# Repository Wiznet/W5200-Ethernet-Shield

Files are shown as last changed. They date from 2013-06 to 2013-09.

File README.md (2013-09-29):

# W5200 Ethernet Shield
W5200 Ethernet Shield is compatible with Official [Arduino Ethernet Shield](http://arduino.cc/en/Main/ArduinoEthernetShield) and support fast SPI and 8 sockets. 

W5200 Ethernet Shield

## Hardware
These are PCB files for the W5200 Ethernet Shield for Arduino. The files were created in the free & low cost EagleCad software available from [CadSoft](http://www.cadsoftusa.com/download-eagle/?language=en).

## Software
You need to change the existing W5100 files to W5200 library files.

1. Install W5200 library
   Overwrite w5100.cpp, w5100.h to the "/libraries/Ethernet/utility" folder in your Arduino IDE. 

2. Using the W5200 library and evaluate existing Ethernet example.
   In the Arduino IDE, go to Files->Examples->Ethernet and open any example, compile and upload the file to Arduino board.

3. Note: libraries/Ethernet/Ethernet.h needs the following at line 10 instead of #define MAX_SOCK_NUM 4, since it doesn't #include "w5100.h" anymore:

 `#ifdef W5200`

 `#define MAX_SOCK_NUM 8`

 `#else`
 
 `#define MAX_SOCK_NUM 4`

 `#endif`

## Revision History
Initial Release : 10 June 2013

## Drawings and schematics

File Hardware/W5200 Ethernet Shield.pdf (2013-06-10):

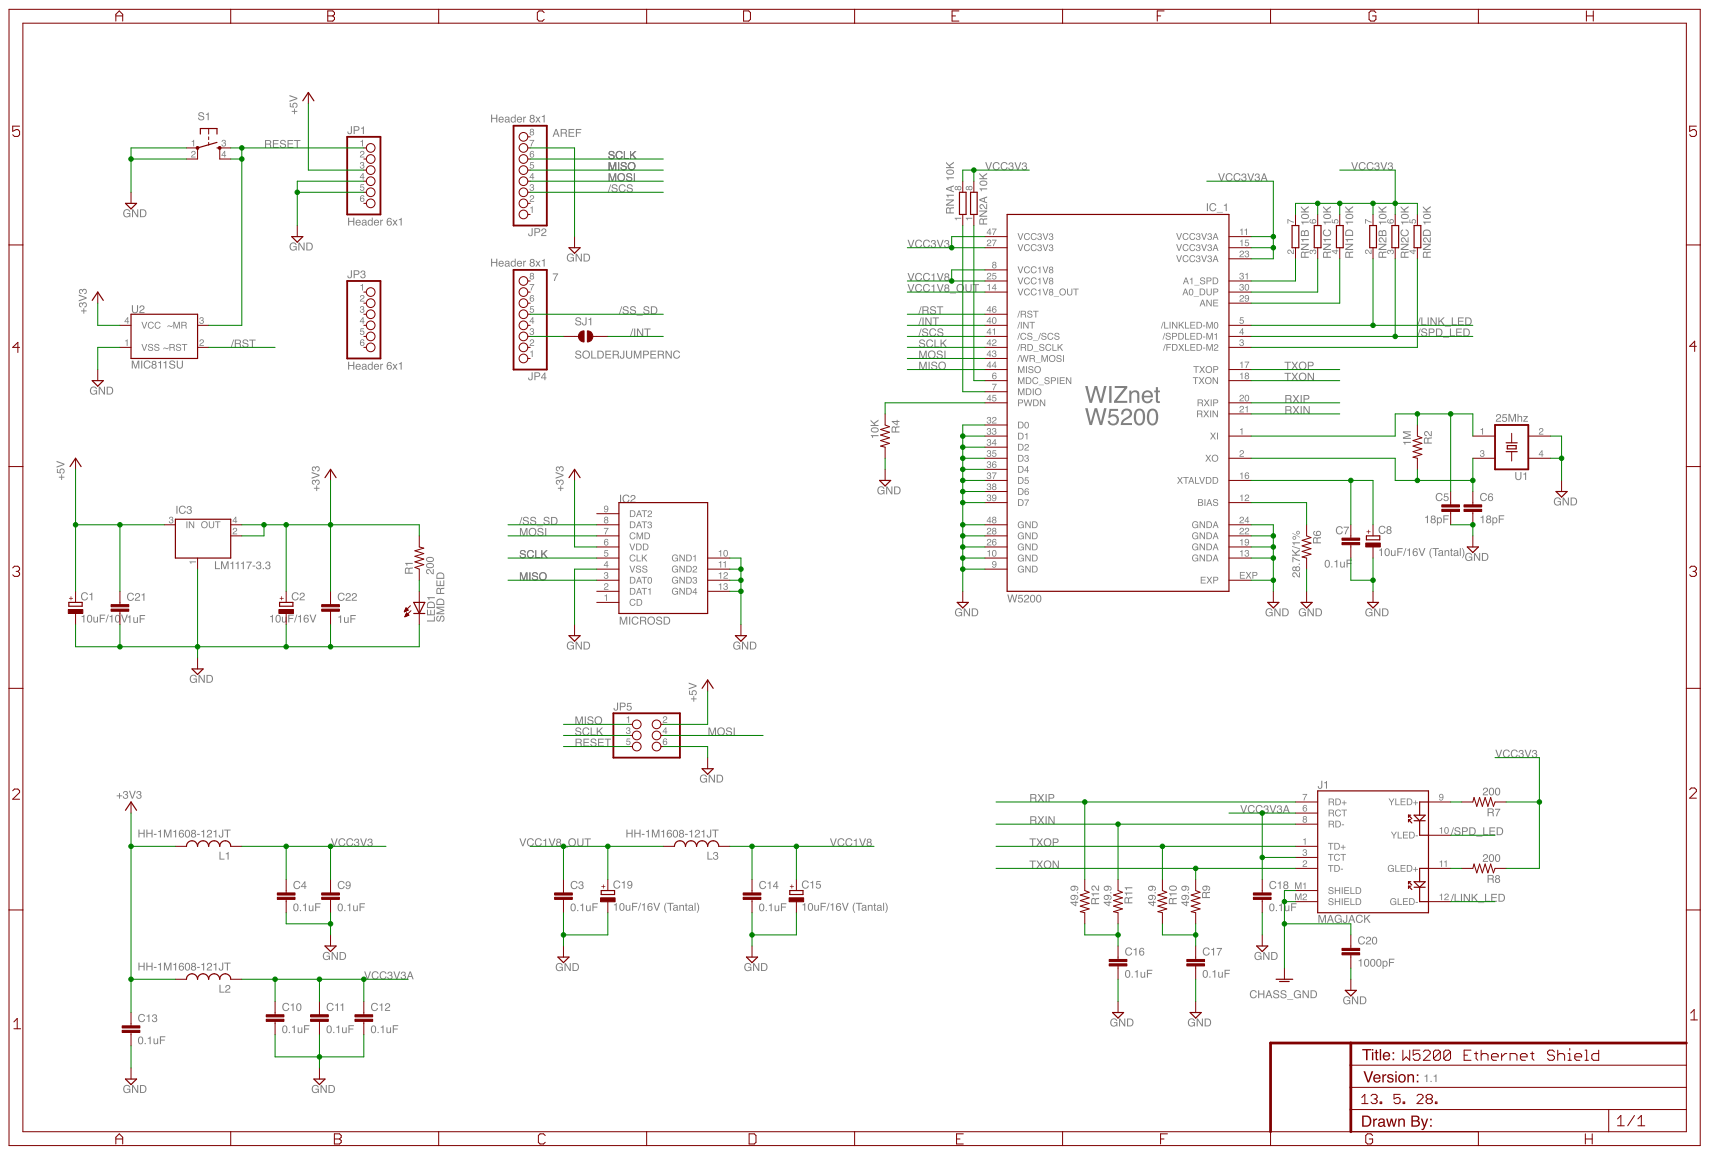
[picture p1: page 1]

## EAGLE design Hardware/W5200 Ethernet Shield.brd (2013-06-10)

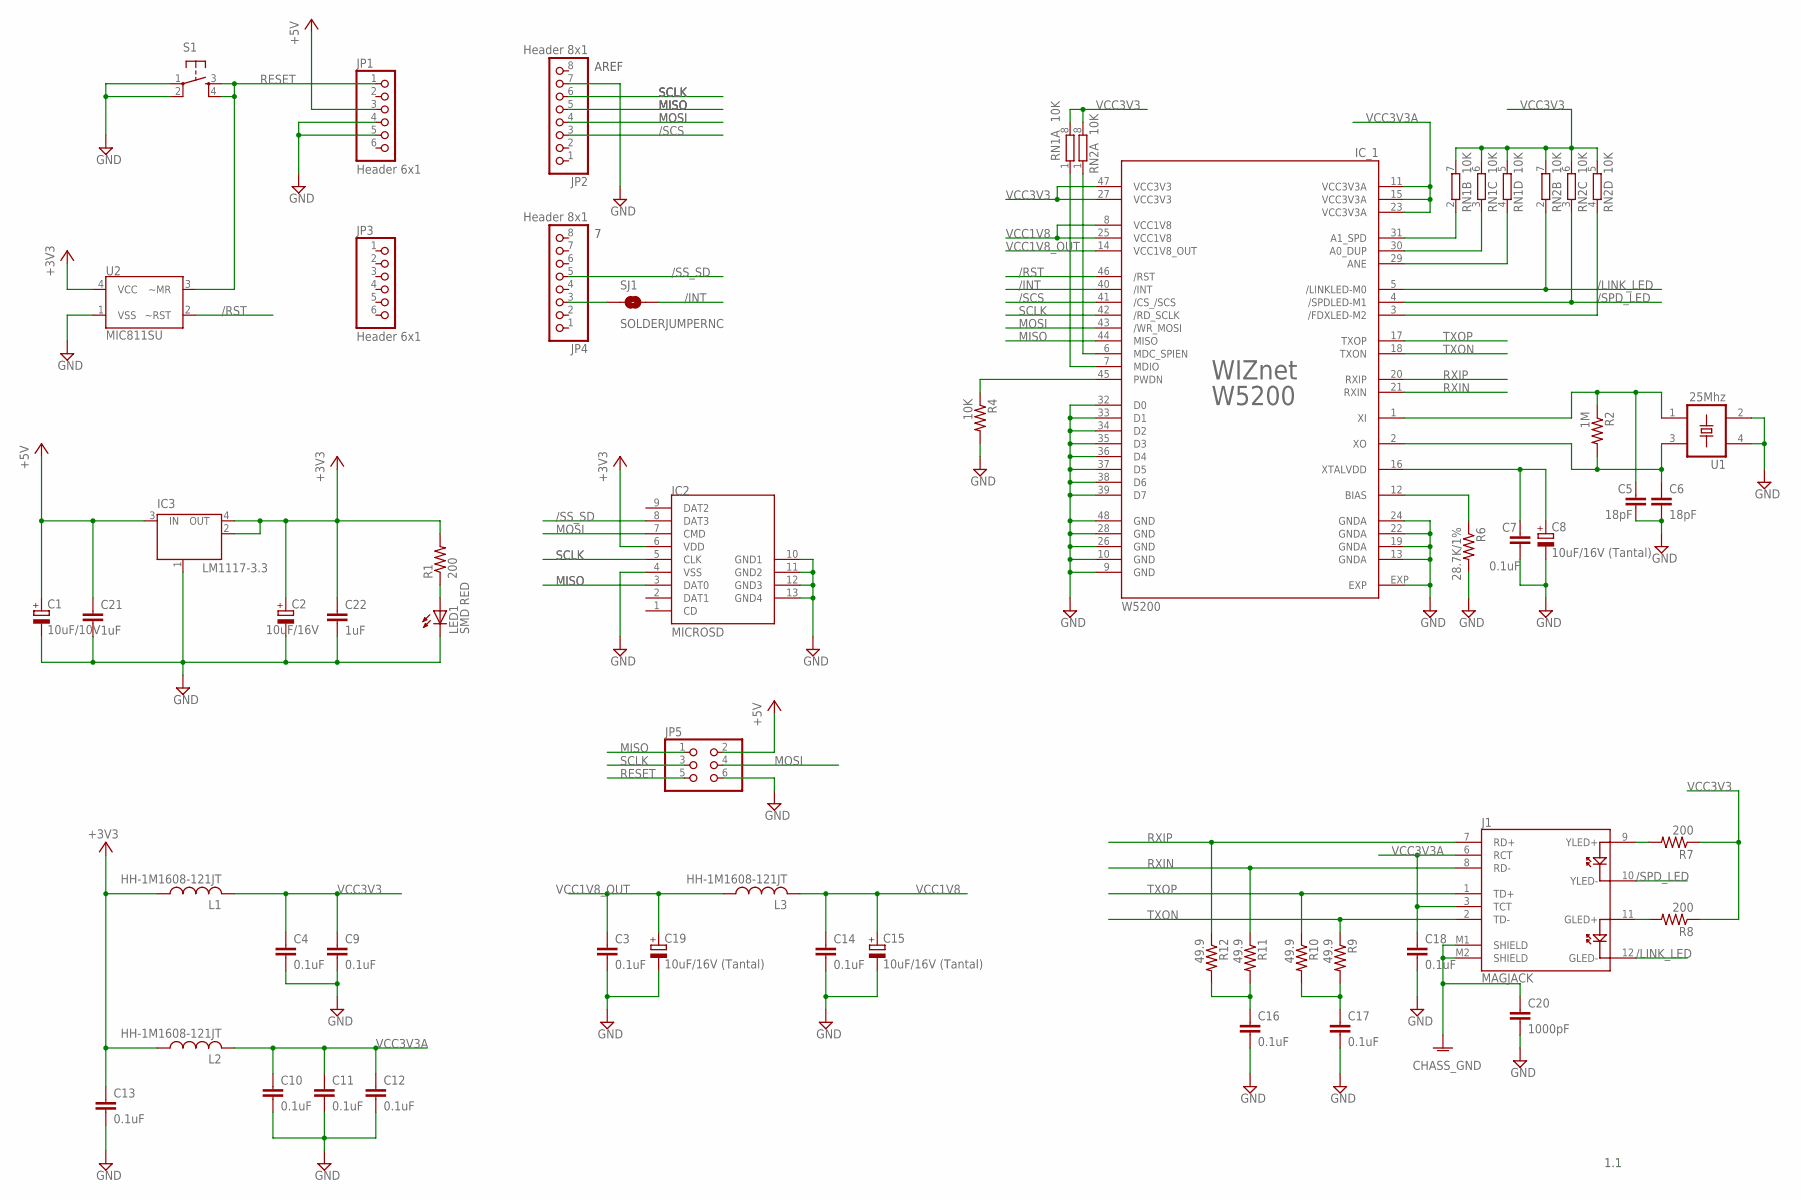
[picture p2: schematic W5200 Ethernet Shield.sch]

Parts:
C1: 10uF/10V; CT3216
C2: 10uF/16V; CT3216
C3, C4, C7, C9, C10, C11, C12, C13, C14, C16, C17, C18: 0.1uF; C0603
C5, C6: 18pF; C0603
C8, C15, C19: 10uF/16V (Tantal); CT3216
C20: 1000pF; C3225
C21, C22: 1uF; C0603
IC2: MICROSD; MSD_SYMBOL_MSDPAC
IC3: LM1117-3.3; SOT223
IC_1: W5200; QFN48
J1: MAGJACK
JP1, JP3: Header 6x1; 1X06
JP2, JP4: Header 8x1; 1X08
JP5: PINHD-2X3; 2X03
L1, L2, L3: HH-1M1608-121JT; L2012C
LED1: SMD RED; CHIP-LED0805
R1, R7, R8: 200; R0603
R2: 1M; R0603
R4: 10K; R0603
R6: 28.7K/1%; R0603
R9, R10, R11, R12: 49.9; R0603
RN1, RN2: 10K; EXBV8V
S1: TAC_SWITCHSMD; TACTILE_SWITCH_SMD
SJ1: SOLDERJUMPERNC; SJ_2S
U1: 25Mhz; CRYSTAL
U2: MIC811SU; SOT143

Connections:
+3V3: C2.+, C13.1, C22.1, IC2.6 (VDD), IC3.2 (OUT), IC3.4 (OUT), L1.1, L2.1, R1.2, U2.4 (VCC)
+5V: C1.+, C21.1, IC3.3 (IN), JP1.3, JP5.2
/INT: IC_1.40 (/INT), SJ1.2
/LINK_LED: IC_1.5 (/LINKLED-M0), J1.12 (GLED-), RN2.2 (1)
/RST: IC_1.46 (/RST), U2.2 (~RST)
/SCS: IC_1.41 (/CS_/SCS), JP2.3
/SPD_LED: IC_1.4 (/SPDLED-M1), J1.10 (YLED-), RN2.3 (1)
/SS_SD: IC2.8 (DAT3), JP4.5
GND: C1.-, C2.-, C3.2, C4.2, C5.2, C6.2, C7.2, C8.-, C9.2, C10.2, C11.2, C12.2, C13.2, C14.2, C15.-, C16.2, C17.2, C18.2, C19.-, C20.2, C21.2, C22.2, IC2.4 (VSS), IC2.10 (GND1), IC2.11 (GND2), IC2.12 (GND3), IC2.13 (GND4), IC3.1 (GND/ADJ), IC_1.9 (GND), IC_1.10 (GND), IC_1.13 (GNDA), IC_1.19 (GNDA), IC_1.22 (GNDA), IC_1.24 (GNDA), IC_1.26 (GND), IC_1.28 (GND), IC_1.32 (D0), IC_1.33 (D1), IC_1.34 (D2), IC_1.35 (D3), IC_1.36 (D4), IC_1.37 (D5), IC_1.38 (D6), IC_1.39 (D7), IC_1.48 (GND), IC_1.EXP, JP1.4, JP1.5, JP2.7, JP5.6, LED1.C, R4.2, R6.2, S1.1, S1.2, U1.2 (GND0), U1.4 (GND1), U2.1 (VSS)
GNDA: C20.1, J1.M1 (SHIELD), J1.M2 (SHIELD)
MISO: IC2.3 (DAT0), IC_1.44 (MISO), JP2.5, JP5.1
MOSI: IC2.7 (CMD), IC_1.43 (/WR_MOSI), JP2.4, JP5.4
unnamed: JP4.3, SJ1.1
unnamed: IC_1.31 (A1_SPD), RN1.2 (1)
unnamed: C6.1, IC_1.2 (XO), R2.2, U1.3 (OUT)
unnamed: C5.1, IC_1.1 (XI), R2.1, U1.1 (TRI)
unnamed: IC_1.30 (A0_DUP), RN1.3 (1)
unnamed: IC_1.29 (ANE), RN1.4 (1)
unnamed: J1.9 (YLED+), R7.2
unnamed: J1.11 (GLED+), R8.2
unnamed: IC_1.7 (MDIO), RN1.1
unnamed: IC_1.12 (BIAS), R6.1
unnamed: C7.1, C8.+, IC_1.16 (XTALVDD)
unnamed: C17.1, R9.2, R10.2
unnamed: LED1.A, R1.1
unnamed: C16.1, R11.2, R12.2
unnamed: IC_1.6 (MDC_SPIEN), RN2.1
unnamed: IC_1.3 (/FDXLED-M2), RN2.4 (1)
PWDN: IC_1.45 (PWDN), R4.1
RESET: JP1.1, JP5.5, S1.3, S1.4, U2.3 (~MR)
RXIN: IC_1.21 (RXIN), J1.8 (RD-), R11.1
RXIP: IC_1.20 (RXIP), J1.7 (RD+), R12.1
SCLK: IC2.5 (CLK), IC_1.42 (/RD_SCLK), JP2.6, JP5.3
TXON: IC_1.18 (TXON), J1.2 (TD-), R9.1
TXOP: IC_1.17 (TXOP), J1.1 (TD+), R10.1
VCC1V8: C14.1, C15.+, IC_1.8 (VCC1V8), IC_1.25 (VCC1V8), L3.2
VCC1V8_OUT: C3.1, C19.+, IC_1.14 (VCC1V8_OUT), L3.1
VCC3V3: C4.1, C9.1, IC_1.27 (VCC3V3), IC_1.47 (VCC3V3), L1.2, R7.1, R8.1, RN1.5 (2), RN1.6 (2), RN1.7 (2), RN1.8 (2), RN2.5 (2), RN2.6 (2), RN2.7 (2), RN2.8 (2)
VCC3V3A: C10.1, C11.1, C12.1, C18.1, IC_1.11 (VCC3V3A), IC_1.15 (VCC3V3A), IC_1.23 (VCC3V3A), J1.3 (TCT), J1.6 (RCT), L2.2

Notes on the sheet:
AREF
SCLK
MISO
MOSI
1.1

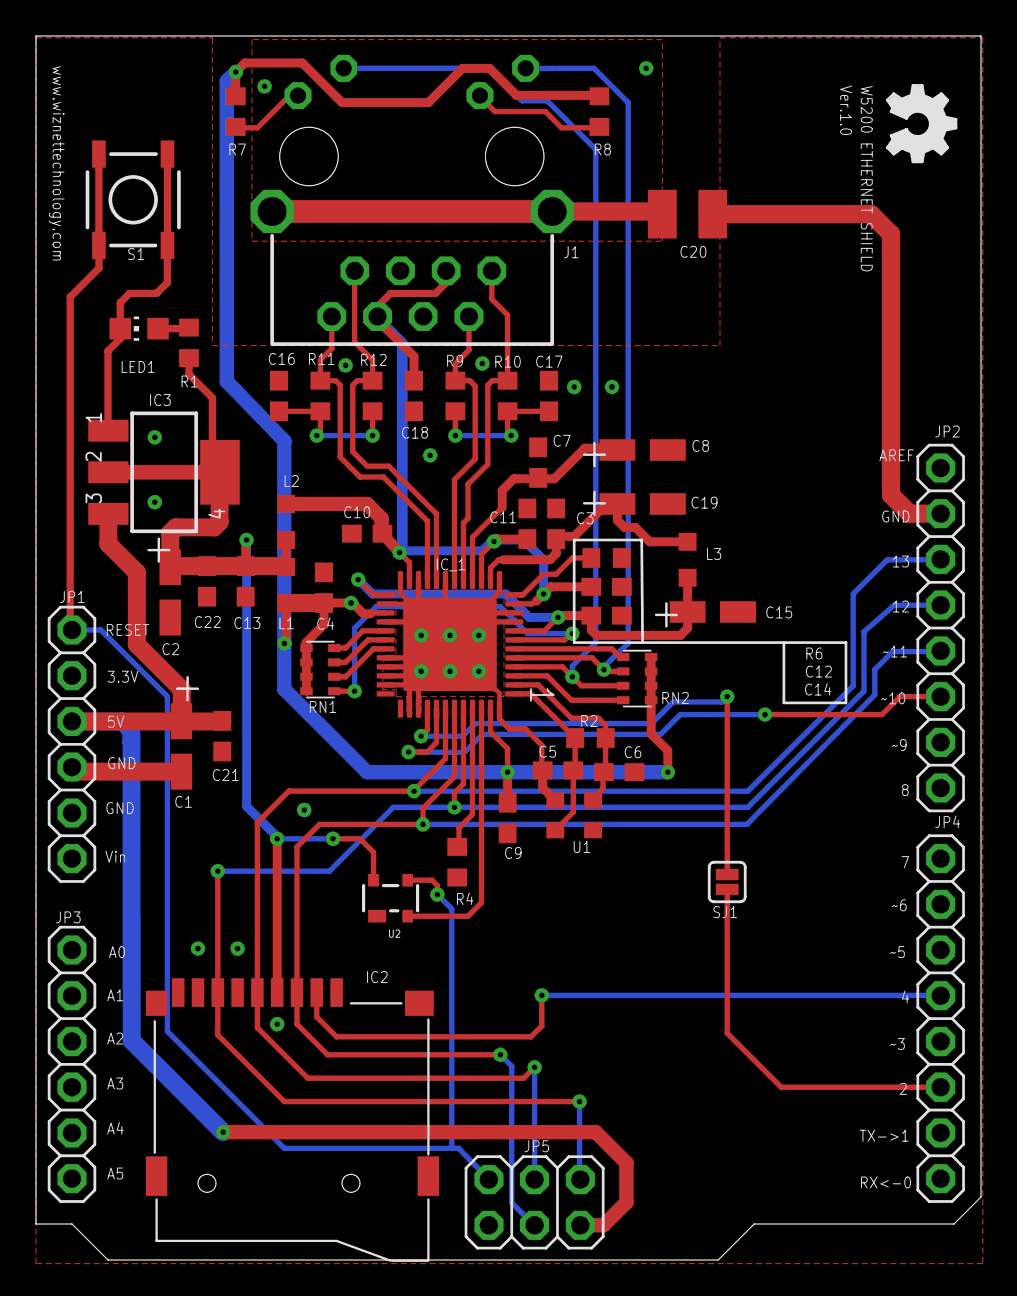
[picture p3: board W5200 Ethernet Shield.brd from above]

Board: 2 copper layers, 52.5 x 68.0 mm, 52 parts (0 on the bottom side), 39 nets.

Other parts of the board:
U$1: OSHW_FILLX150_NOTEXT

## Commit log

2013-06-10 Initial release
    [W5200 Ethernet Shield.brd, W5200 Ethernet Shield.sch]
2013-07-22 Adding S/W lib
    [W5200 Ethernet Shield.brd, W5200 Ethernet Shield.sch]
2013-10-11 update code for Arduino Due

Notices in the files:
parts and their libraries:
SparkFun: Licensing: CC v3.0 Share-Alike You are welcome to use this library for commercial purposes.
